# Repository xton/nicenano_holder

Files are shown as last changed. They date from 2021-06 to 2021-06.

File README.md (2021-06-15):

# Plank Planck Wireless Mod

A while ago I made a keyboard case for a [Planck](https://olkb.com/collections/planck) out of a old redwood plank (a plank Planck!) with a big flat area for mousing. Good for couch gaming. Kind of like a home brew Razer Turret. Worked pretty well but very long USB cables only go so far.

Recently, the [ZMK](https://zmk.dev/) project and cheap tiny microcontrollers with onboard Bluetooth like the [nice!nano](https://nicekeyboards.com/nice-nano/) are making custom wireless keyboards more accessible.

Now, the Plank has its MCU soldered in, buuut it exposes handy contacts for the matrix. So! Some creative rewiring, some sharp chisels, a router plane, a custom 3D printed cover, and a bunch of hours where other people were holding the baby, and I’ve got myself a wireless ortholinear couch gaming keyboard.

# This Repo...

Has the model for the 3d printed cover/mcu mount. Enjoy! Woodworking, wiring, and zmk mods left as an exercise the reader.

# Assembly

1. Solder everything. Row and column headers to your choice of GPIO pins on the MCU. Bat+ and bat- to your battery. Some short leads to RST and GND.
2. Carve/route your mcu/wiring recess into your keyboard case. 
3. Trim some standard outdoor wood screws so they won't penetrate the top of the case (or, y'know, get the proper screws, but I had a ton of these!). Drill the appropriate pilot holes in your case.
4. Thread the mcu and wire bundle through the front of the case so it dangles out the back. 
5. Push a tactile switch in to the small hollow in the case so the legs penetrate the two holes (you may need to adjust the dimensions of this for the switches you have on hand).
6. Slide the wired-up MCU into the rails in the case. The USB C port should align with the hole. Lock the MCU in place by sliding the extra 3d printed slab in behind it. 
7. Solder the reset leads to the reset switch.
8. Screw everything together and enjoy!

# Gallery

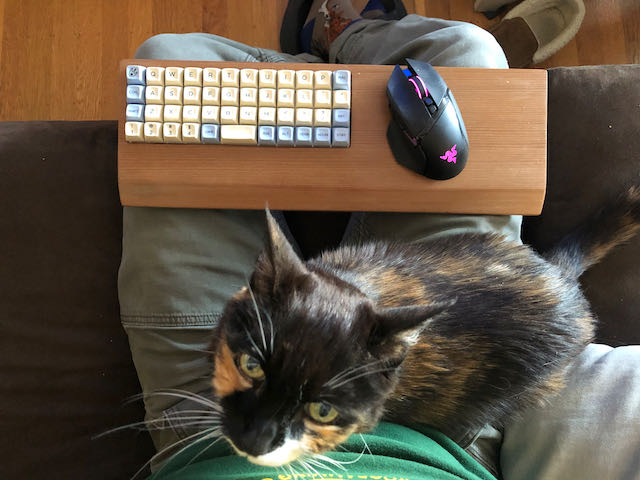
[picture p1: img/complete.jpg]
complete

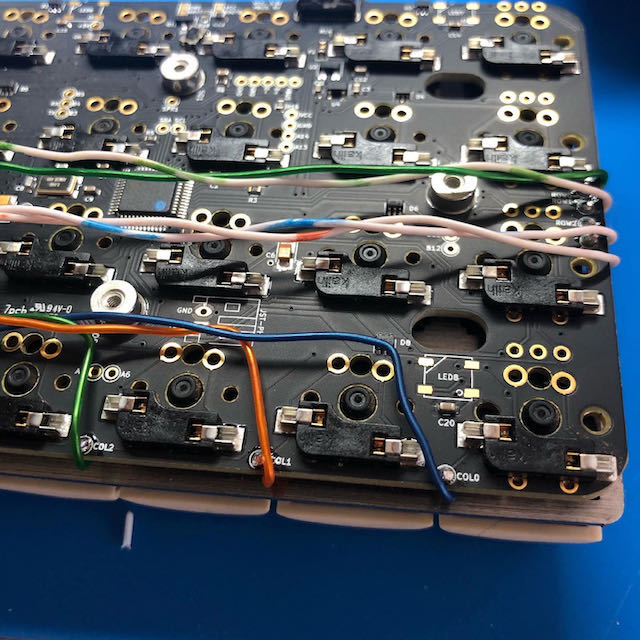
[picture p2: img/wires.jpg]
wires

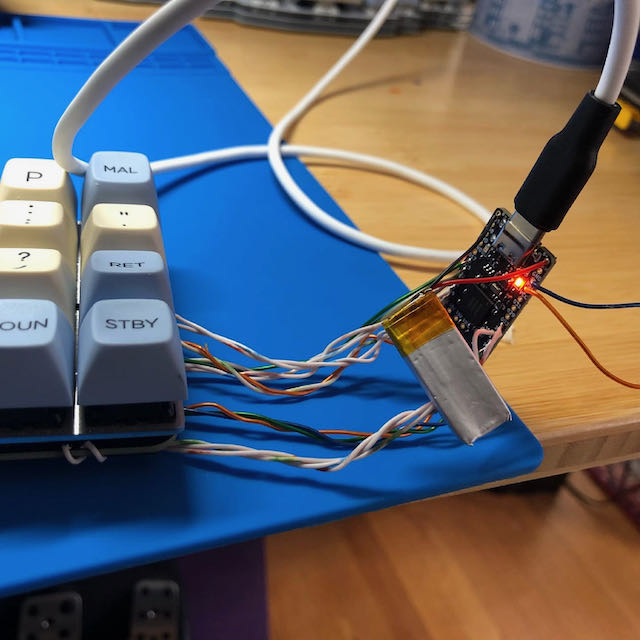
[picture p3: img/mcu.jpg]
mcu

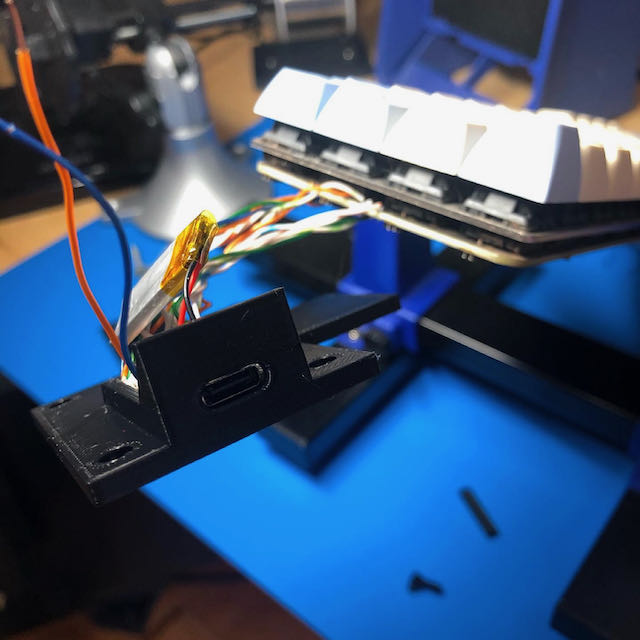
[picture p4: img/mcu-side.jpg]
mcu with case

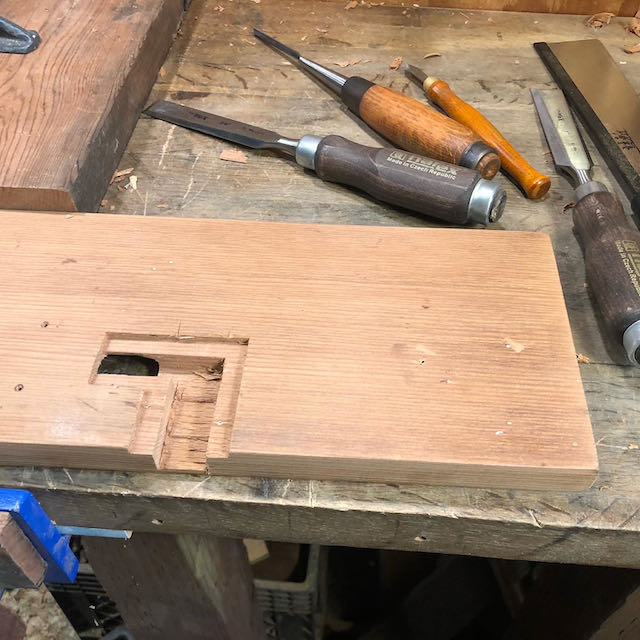
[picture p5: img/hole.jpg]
hole

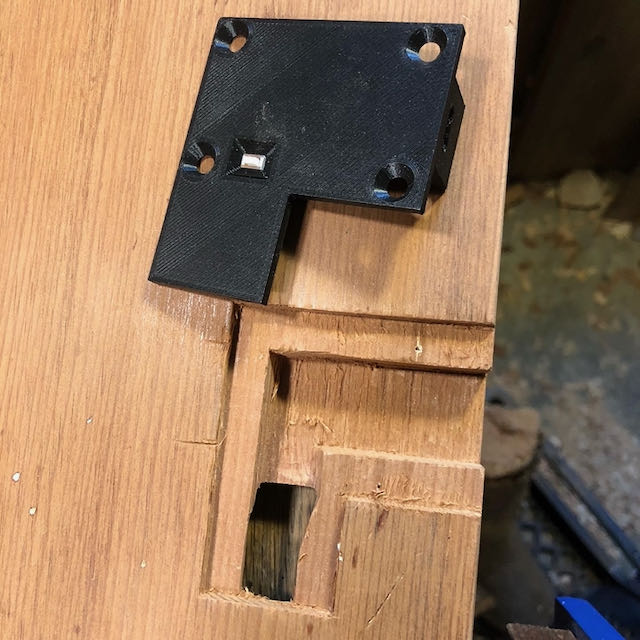
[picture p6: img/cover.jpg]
cover

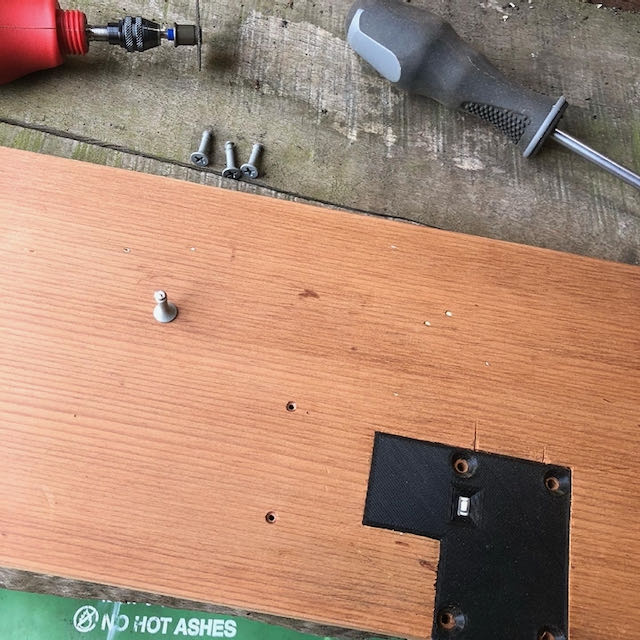
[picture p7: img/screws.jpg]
screws

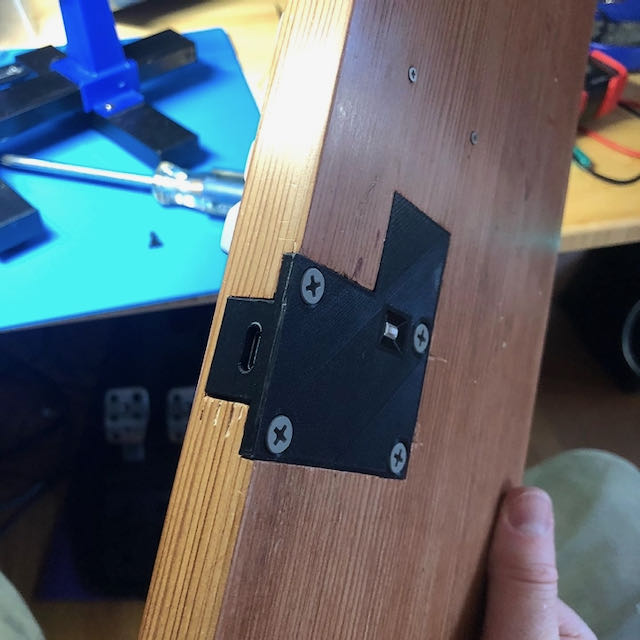
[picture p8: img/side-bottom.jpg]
assembled

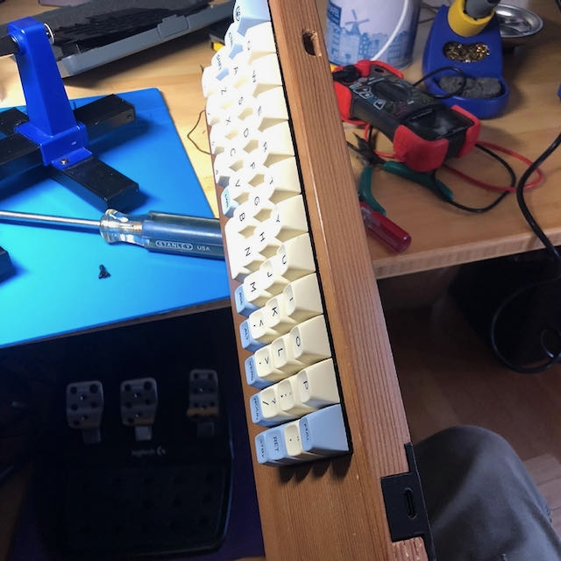
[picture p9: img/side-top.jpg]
assembled 2


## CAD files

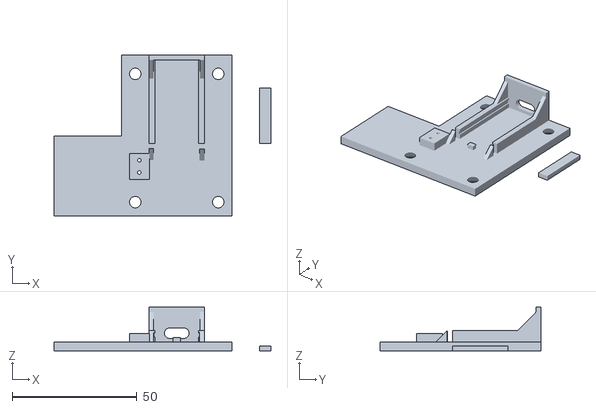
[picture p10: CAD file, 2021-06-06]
nn_holder.stl
86.8 x 64.3 x 17.5

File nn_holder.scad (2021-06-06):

// dimensions of the nice!nano mcu
nn_w = 18.2;
nn_l = 33.3;
nn_d = 1.6;
nn_usb_d = 3.15;
nn_usb_w = 8.9;

// tolerances
tol = 0.2;
$fs = 0.5;

// external dimensions
wall = 2.0;

// countersunk screw 
screw_r = 2.3;
countersink_r = 4.7;

// holder
holder_inset = 0.4;
padding_top = 1.0;
padding_bottom = 2.0;

// backstop
// backstop_screw_r = 3.2/2 + 2*tol;
// backstop_screw_head_r = 7.65/2 + tol;
bs_w = 3.0;
bs_l = 2.0;

// front plate
box_height = 10.0;
cable_port_d = 0.3;

// bottom plate
skirt = 11.0;
bp_padding_bottom = 20.0 - wall; // oops. bad measurement. adjusting...
bp_left_shaft = 40.0;
bp_left_shaft_w = 10;
floor_d = 3.5;

// reset switch

rs_w = 3.5 + 2*tol;
rs_l = 6 + 2*tol;
rs_d = 3.5;
rs_inset_d = 1.5;
rs_inset = 3;
rs_leg_d = 1.5; // leg hole diameter


// todo2
// - [x] bottom plate
// - [x] screw countersinks
// - [x] front plate
// - [x] mcu side holder
// - [x] mcu backstop block
// - [ ] reset switch hollow (box w/ 2 holes)
// - [x] pick out and measure both screws

// modules

module holder_side(){
    rotate([90,0,0]) mirror([0,0,1]){
    linear_extrude(height=nn_l){
        polygon(points=[
            [0-wall,0], // origin
            [0-wall,padding_top + padding_bottom + nn_d], // top left
            [holder_inset,padding_top + padding_bottom + nn_d], // top right

            [holder_inset,  padding_bottom + nn_d],
            [-1*tol/2, padding_bottom + nn_d],
            [-1*tol/2, padding_bottom],
            [holder_inset, padding_bottom],
            [holder_inset, 0]
        ]);
    };
    };
};

module holder() {
    holder_side();
    translate([nn_w,0,0]) mirror([1, 0, 0]) {
        holder_side();
    }
}

module support(side) {
    rotate([0,90,0]) linear_extrude(wall-tol) polygon(points=[
        [0,0], [0,-side],[-side,0]
    ]);
}

module front_plate() {
    translate([-1*wall, nn_l, 0]) union() {
        difference(){
            cube([nn_w + 2*wall, wall, box_height+wall*2]);
            # translate([nn_usb_d/2 + wall + (nn_w - nn_usb_w) / 2,  0, nn_usb_d/2 + padding_bottom]) rotate([90,0,0]) mirror([0,0,1]) linear_extrude(wall+tol) hull() {
                circle(d=nn_usb_d+2*(tol+cable_port_d));
                translate([nn_usb_w-nn_usb_d,0]) circle(d=nn_usb_d+2*(tol+cable_port_d));
            }
        }
        support(box_height+wall);
        translate([nn_w+wall+tol,0,0]) support(box_height+wall);
    }
}


module backstop() {
    translate([0,-wall]) union() {
        translate([nn_w/2 - bs_w/2,-bs_l,0]) cube([bs_w, bs_l,padding_bottom-tol]);
        translate([-wall,-tol/2,0]) support(padding_top + padding_bottom + nn_d);
        translate([nn_w+wall+tol/2,0,0]) translate([-wall,-tol,0]) support(padding_top + padding_bottom + nn_d);
    }

    // separate bar to lock things in place
    translate([nn_w+wall+skirt*2, 0, -floor_d]) {
        cube([padding_top + padding_bottom + nn_d, nn_w+wall*2, wall]);
        
    }
}


module countersink() {
    #cylinder(h=floor_d,r1=screw_r,r2=countersink_r);
}


module truncated_pyramid(sides,outset) {
    // from example: https://en.wikibooks.org/wiki/OpenSCAD_User_Manual/Primitive_Solids#polyhedron
    // top face is outset `outset` units from bottom.
    polyhedron( [
            [  0,  0,  0 ],  //0
            [ sides.x,  0,  0 ],  //1
            [ sides.x,  sides.y,  0 ],  //2
            [  0,  sides.y,  0 ],  //3
            [  0-outset,  0-outset,  sides.z ],  //4
            [ sides.x+outset,  0-outset,  sides.z ],  //5
            [ sides.x+outset,  sides.y + outset,  sides.z ],  //6
            [  0-outset,  sides.y + outset,  sides.z ]   //7
        ],
        [
            [0,1,2,3],  // bottom
            [4,5,1,0],  // front
            [7,6,5,4],  // top
            [5,6,2,1],  // right
            [6,7,3,2],  // back
            [7,4,0,3]  // left
        ]);
}


rs_origin = [0-rs_w,0-bp_padding_bottom+bp_left_shaft_w+wall-rs_l, floor_d];

module rs_hollow() {
    #translate(rs_origin) rotate([0,0,90]) translate([0,0,0-rs_d - rs_inset_d]) {
        cube([rs_l,rs_w,rs_d + rs_inset_d]);
        translate([0,0,rs_d]) truncated_pyramid([rs_l, rs_w, rs_inset_d], rs_inset);
        translate([rs_leg_d/2, rs_w/2, 0-floor_d]) cylinder(d=rs_leg_d, h=floor_d);
        translate([rs_l-rs_leg_d/2, rs_w/2, 0-floor_d]) cylinder(d=rs_leg_d, h=floor_d);
    }
}

module rs_hull() {
    translate(rs_origin) rotate([0,0,90]) mirror([0,0,1]) translate([0-wall, 0-wall, 0]){
        cube([rs_l+2*wall,rs_w+2*wall,wall+rs_d + rs_inset_d]);
    }

}

module bottom_plate() {
    mirror([0, 0, 1]) difference() {
        union(){
            linear_extrude(floor_d) polygon(points=[
                [0 - wall - skirt, nn_l + wall],
                [nn_w + wall + skirt, nn_l + wall],
                [nn_w + wall + skirt, 0-bp_padding_bottom-skirt],
                [0-bp_left_shaft, 0-bp_padding_bottom-skirt],
                [0-bp_left_shaft, 0-bp_padding_bottom+bp_left_shaft_w+skirt],
                [0-wall-skirt, 0-bp_padding_bottom+bp_left_shaft_w+skirt],
            ]);
            rs_hull();
        }

        // screws
        translate([skirt/-2-wall,nn_l-skirt/2,0]) countersink();
        translate([skirt/2+nn_w+wall,nn_l-skirt/2,0]) countersink();
        translate([skirt/2+nn_w+wall,0- bp_padding_bottom- skirt/2,0]) countersink();
        // translate([0-bp_left_shaft+skirt/2,0- bp_padding_bottom- skirt/2,0]) countersink();
        // translate([0-bp_left_shaft+skirt/2,0-bp_padding_bottom+bp_left_shaft_w+skirt/2,0]) countersink();
        translate([0-wall-skirt/2,0- bp_padding_bottom- skirt/2,0]) countersink();

        rs_hollow();
    }
        
    
        
}


// main

holder();
backstop();
front_plate();
bottom_plate();


// todo: 
// - [x] supports on side of frontplate
// - [x] tighter holder
// - [s] redesign backstop
// - [x] move rest switch box

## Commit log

2021-06-03 new plan
    [nn_holder.scad]
2021-06-05 a bunch of adjustments. new support structure
    [nn_holder.scad]
2021-06-06 include stl file
    [nn_holder.stl]
